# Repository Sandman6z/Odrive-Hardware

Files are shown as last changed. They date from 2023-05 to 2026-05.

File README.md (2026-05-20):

# ODriveHardware

**!Bug !Bug !Bug**

When I design my PCB project, I forked from Odrive official repository [ODriveHardware](https://github.com/odriverobotics/ODriveHardware) .
However, the PCB project under /v3 have some different with schmetic in /v3/v3.5docs.
After I find too much data, and ask AI, and other opensource projects, like `oshwhub`. They all told me that use v3.5 schmetic not the one under repository root.
Such a big oolong.

***And another one thing. The schematics of version 3.6 are basically the same as those of version 3.5. Only the voltage resistance of the capacitor has been changed due to firmware adjustments.***

---

This project is all about accuratly driving brushless motors, for cheap. The aim is to make it possible to use inexpensive brushless motors in high performance robotics projects.

If you want to get your hands on a board, check out [this post](https://hackaday.io/project/11583-odrive-high-performance-motor-control/log/40702-boards-and-development).

This repository contains the circuit board design of ODrive. The other related repositories are:
* [ODriveFirmware](https://github.com/madcowswe/ODriveFirmware): Firmware that runs on the board.
* [ODrive](https://github.com/madcowswe/ODrive): Configuration and analysis scripts that runs on a PC.

There is also [ODriveFPGA](https://github.com/madcowswe/ODriveFPGA), which contains the FPGA logic and software that runs on the FPGA based ODrive. This is not currently in development, but may be resumed at some later date.

## Odrive v3 board
The pinout from the microcontroller to the board is documented [here](https://docs.google.com/spreadsheets/d/1QXDCs1IRtUyG__M_9WruWOheywb-GhOwFtfPcHuN2Fg/edit?usp=sharing).

### ODrive v3.1 errata
* The silkscreen labels for the encoders (M0, M1) are reversed.
* The output impedence of the current amplifiers were not considered when designing the post-amplifier filters. Hence the response is about 5x slower than designed. Max allowed modulation index is therefore about 50%.

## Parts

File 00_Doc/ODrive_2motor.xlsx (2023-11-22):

Quantity | Designator | Description | Voltage - Rated | Comment | LibRef
58 | C1, C2, C3, C4, C5, C6, C7, C8, C9, C10, C11, C12, C13, C14, C15, C16, C17, C18, C22, C24, C25, C26, C27, C28, C30, C31, C32, C33, C34, C35, C36, C37, C38, C39, C40, C41, C42, C43, C45, C46, C47, C48, C49, C50, C51, C52, C53, C54, C55, C56, C57, C58, C59, C60, C61, C62, C63, C64 | Capacitor, CAP CER 82PF 100V NP0 0603, CAP CER 0.1UF 50V X7R 0603, CAP CER 4.7UF 35V X5R 0805, CAP CER 270PF 50V NP0 0603, CAP CER 2.2UF 16V X5R 0603, CAP CER 0.022UF 50V X7R 0603, CAP CER 2200PF 50V NP0 0603 |  | 2.2uF, Cap, 1uF, 10uF, 100nF, 100uF, 330uF | Cap
1 | C29 | CAP TANT 68UF 16V 20% 2312 250mOhm |  | 68uF | T495C686M016ATE250
3 | CE1, CE2, CE3 | Polarized Capacitor (Axial) |  | 470uF | Cap Pol
2 | D1, D2 | Rectifier Diode, Single, 40 V, 1 A, SOD-123FL, 2, 550 mV |  |  | MBR140SFT1G
2 | FB1, FB2 | 标称阻抗@测试频率:600Ω@100MHz;误差:±25%;直流电阻(RDC):250mΩ;额定电流:2A;电路数:1; |  | L0805, L0603 | Ferrite Bead
4 | FID1, FID2, FID3, FID4 | 1mm Fiducial with 2mm soldermask, 3mm keepout |  | MARK Point | FIDUCIAL
4 | H1, H2, H3, H4 | M3 Hole with no copper |  |  | M3 Hole
1 | J1 |  |  | XT60PB | XT60PB-F/M
1 | J2 | CONN-SMD_5P-P1.25_532610571-2 |  | SH1.0-5P | SH1.0-5P
1 | J3 | Header, 16-Pin |  | Leftheader | Header 16
2 | J14, J19 | 驱动器端 |  | MR30PW-F | MR30PW-F
1 | J23 |  |  | 2square_pads | 2square_pads
2 | J100, J101 |  |  | GH1.25-5P | GH1.25-5P
1 | L2 | INDUCTOR 22UH 1.4A 175.5 MOHM |  | 22uH | NR6028T220M
1 | LED1 | 发光颜色: |  | GREEN | LED
14 | Q2, Q4, Q6, Q8, Q10, Q12, Q14, Q16, Q18, Q20, Q22, Q24, Q25, Q27 | MOSFET – Power, Single, N-Channel, SO-8 FL 30 V, 93 A |  | NTMFS4935NT1G | MOSFET-N
55 | R1, R2, R3, R4, R6, R7, R8, R9, R10, R11, R12, R13, R14, R15, R16, R17, R18, R19, R20, R21, R22, R23, R24, R25, R26, R27, R28, R29, R30, R32, R33, R34, R35, R36, R37, R38, R39, R40, R41, R42, R43, R44, R45, R46, R47, R48, R50, R51, R52, R53, R54, R55, R56, R57, R221 | Resistor, RES SMD 0.0005 OHM 1% 3W 2512 |  | 22R, Res, Ω ±1% 100mW | Res
3 | RT1, RT2, RT3 | THERMISTOR 10K OHM NTC 0402 SMD |  | NCP15XH103F03RC | TEMP RES
1 | U2 | ARM Cortex-M4 32-bit MCU+FPU, 210 DMIPS, 1024 kB Flash, 192 kB Internal RAM, 51 I/Os, 64-pin LQFP, -40 to 85 degC, Tray |  | STM32F405RGT6 | STM32F405RGT6
1 | U3 | LP5907MFX-3.3/NOPB SOT23-5 |  | LP5907MFX-3.3/NOPB | LP5907
2 | U4, U5 | MOTOR DRIVER, 3PH, 56HTSSOP |  | DRV8301 | DRV8301
1 | U6 | DRIVER, MOSFET, HALF BRIDGE, WSON-8, 1A |  | LM5109BSD/NOPB | LM5109BSD/NOPB
1 | U7 | ANALOG DEVICES Current Sense Amplifier, Bidirectional, 1, 130 µA, NSOIC |  | AD8418WBRZ | AD8418WBRZ
1 | U8 |  |  | 1117 | 1117
1 | USB1 |  |  | USB-C 16P | USB-C 16P
1 | X1 | Crystal 8MHz ±10ppm 10pF 200 Ohm -10°C ~ 60°C Surface Mount 4-SMD, No Lead (DFN, LCC) |  | X3225 | X3225

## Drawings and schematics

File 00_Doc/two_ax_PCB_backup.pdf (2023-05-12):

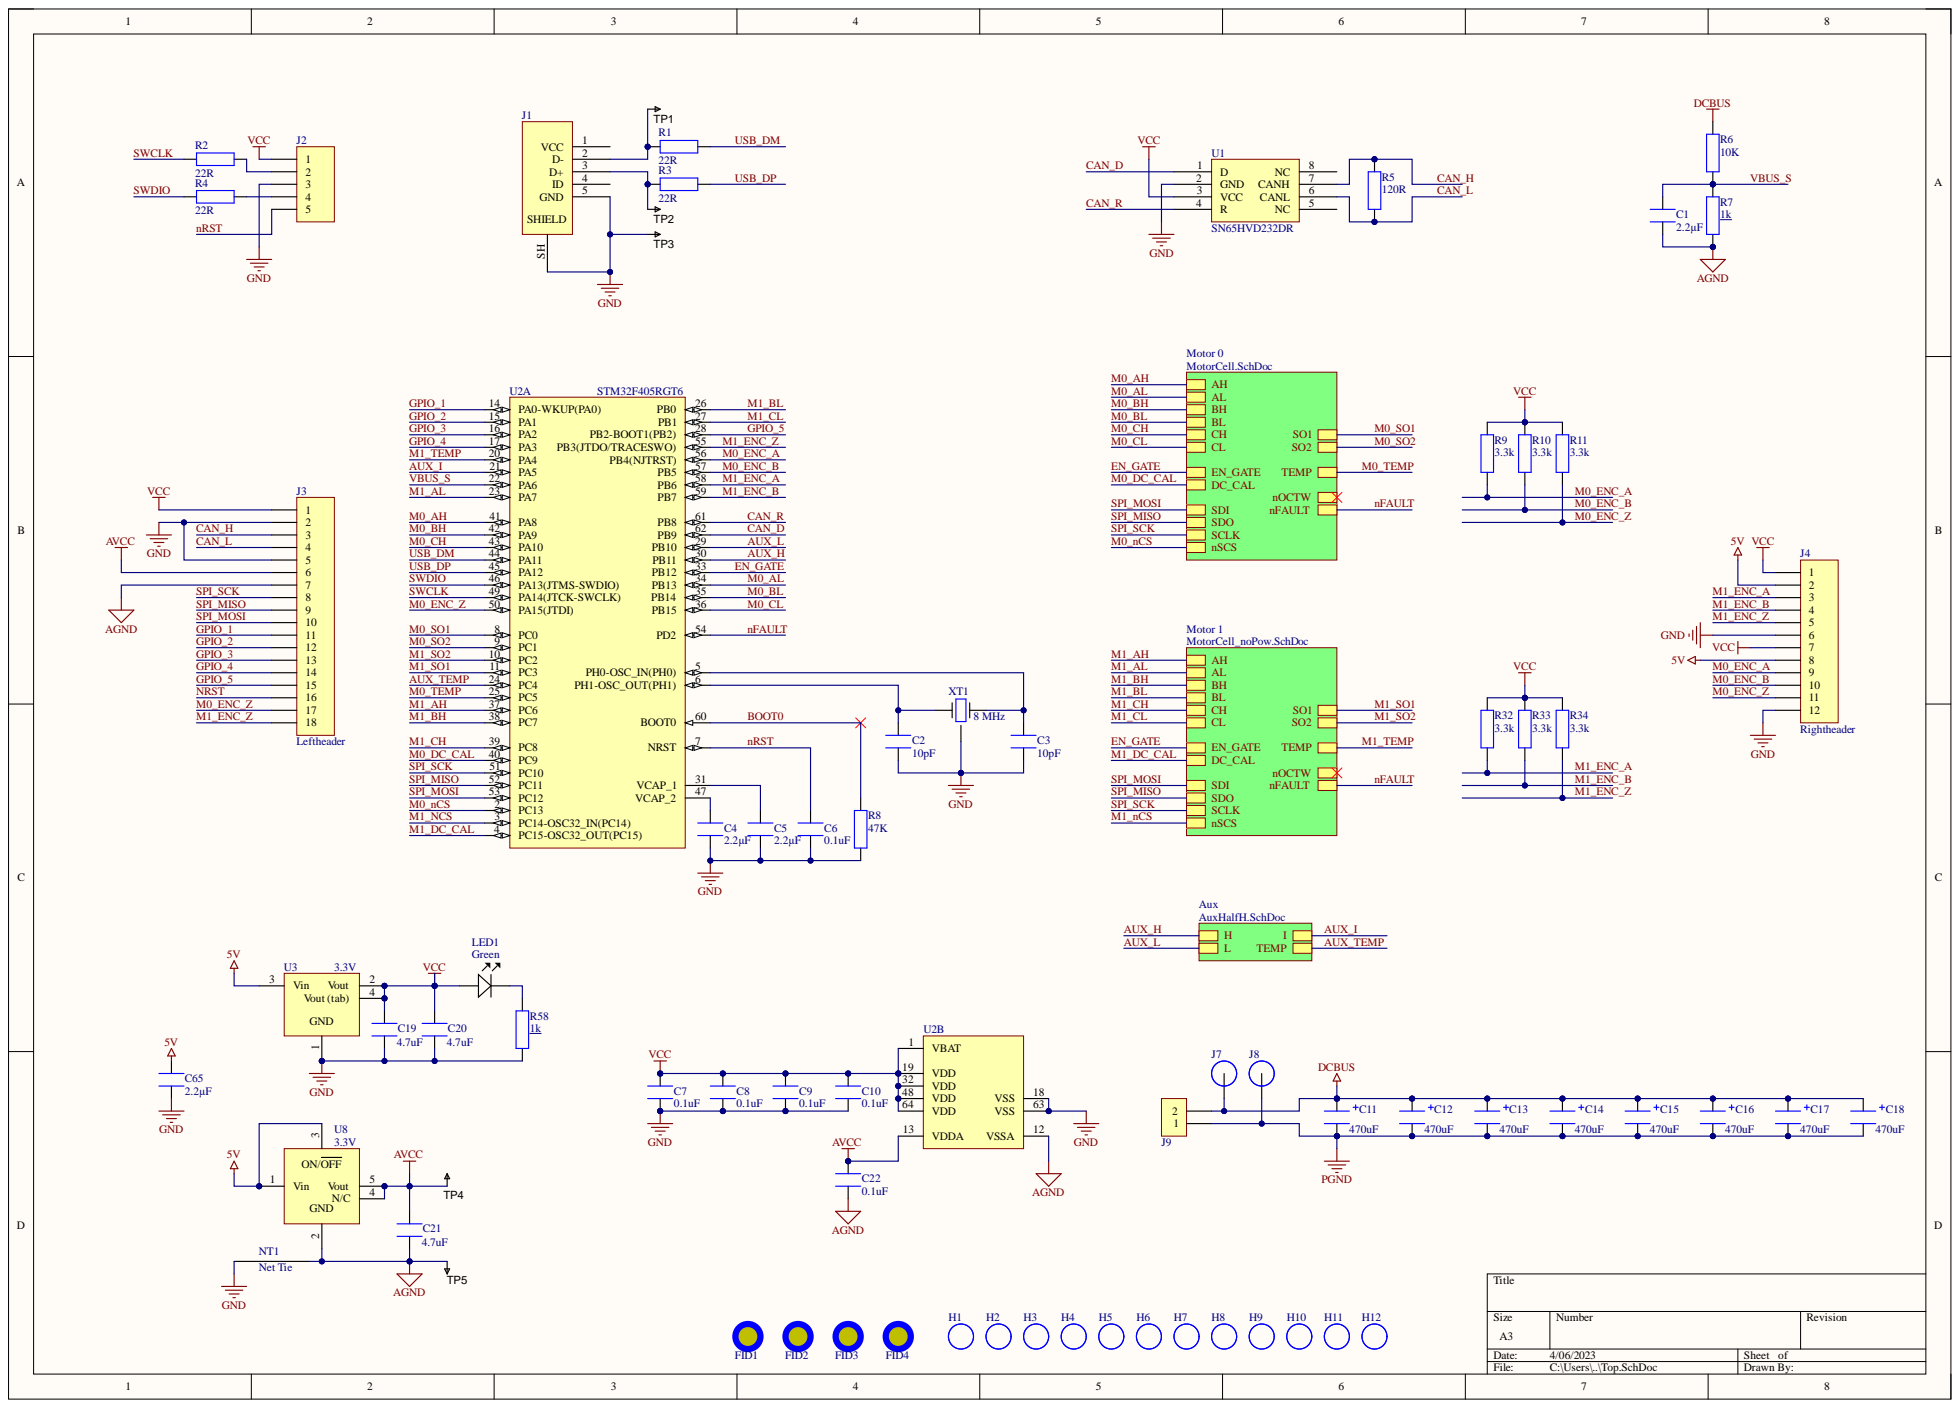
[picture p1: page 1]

3Lefthead 123456789 1011 12 13 14 15 16 17 18 | M0_A H | C A N_R

SPI_SC K | SWC L K | M0_B L N C_A
SPI_M ISO | M0_E N C_Z | M0_C L M1_E N C_B

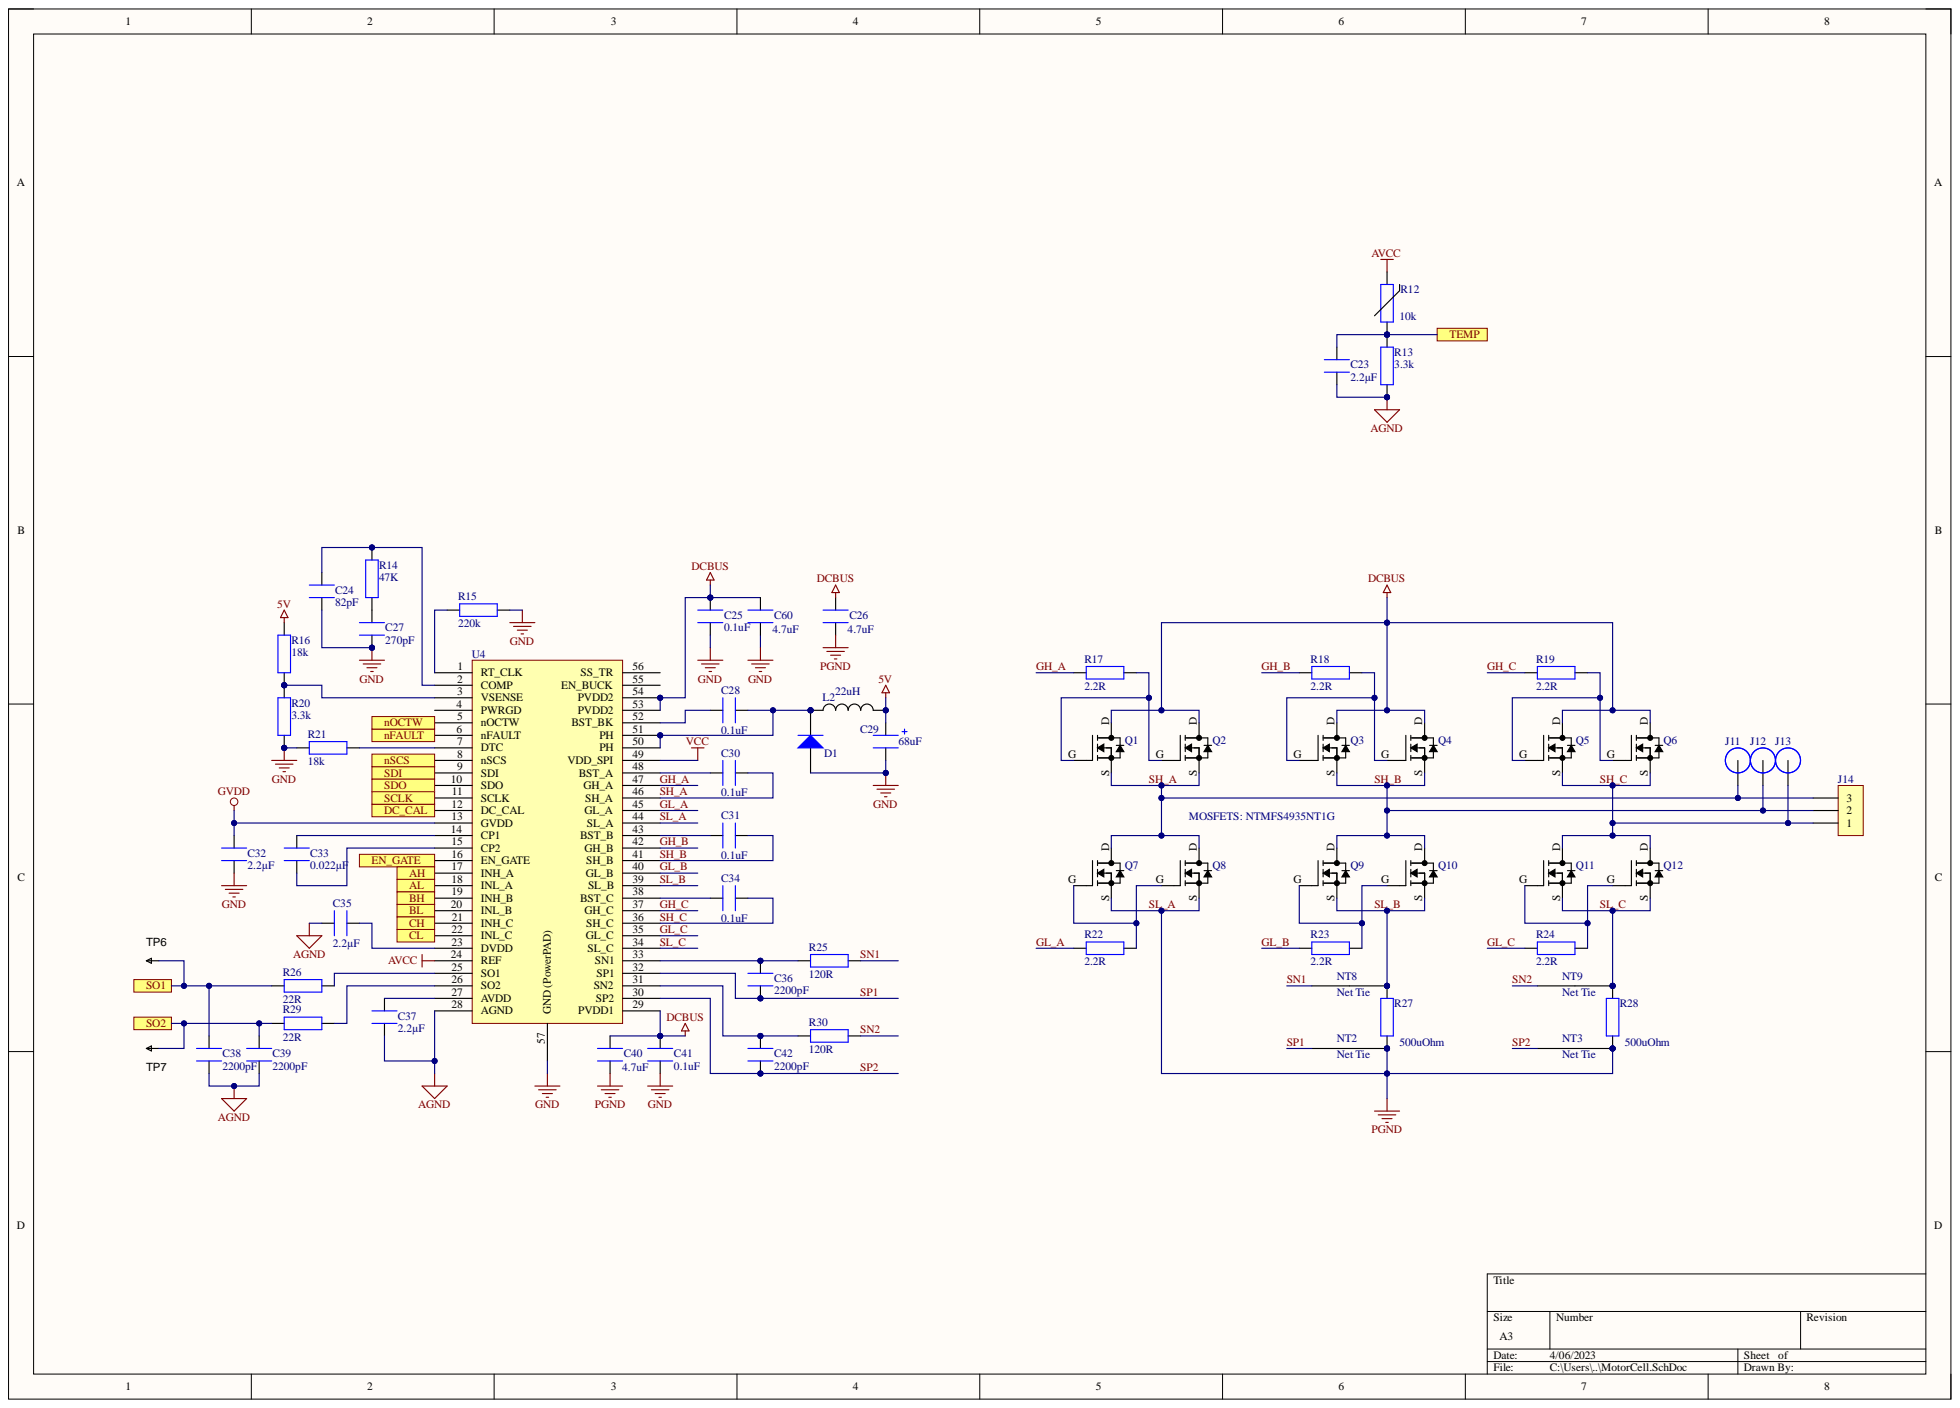
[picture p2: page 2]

PWRGD 4

nOCTW | | nOCTW 5
nFAULT | | DTC 7
nSCS | | nSCS 8
SDI | | SDI 9

nFAULT 6 | | VCC

DC_CAL | DC_CAL 12 | GL_A C31

GVDD 13 | SL_A
CP1 14
CP2 15 | | GH_B | 0.1uF

EN_GATE | | EN_GATE 16 | | SH_B

INH_A 17 | GL_B

AH | | INL_A 18 | SL_B
BH | INH_B 19

C37 | DCBUS | R30

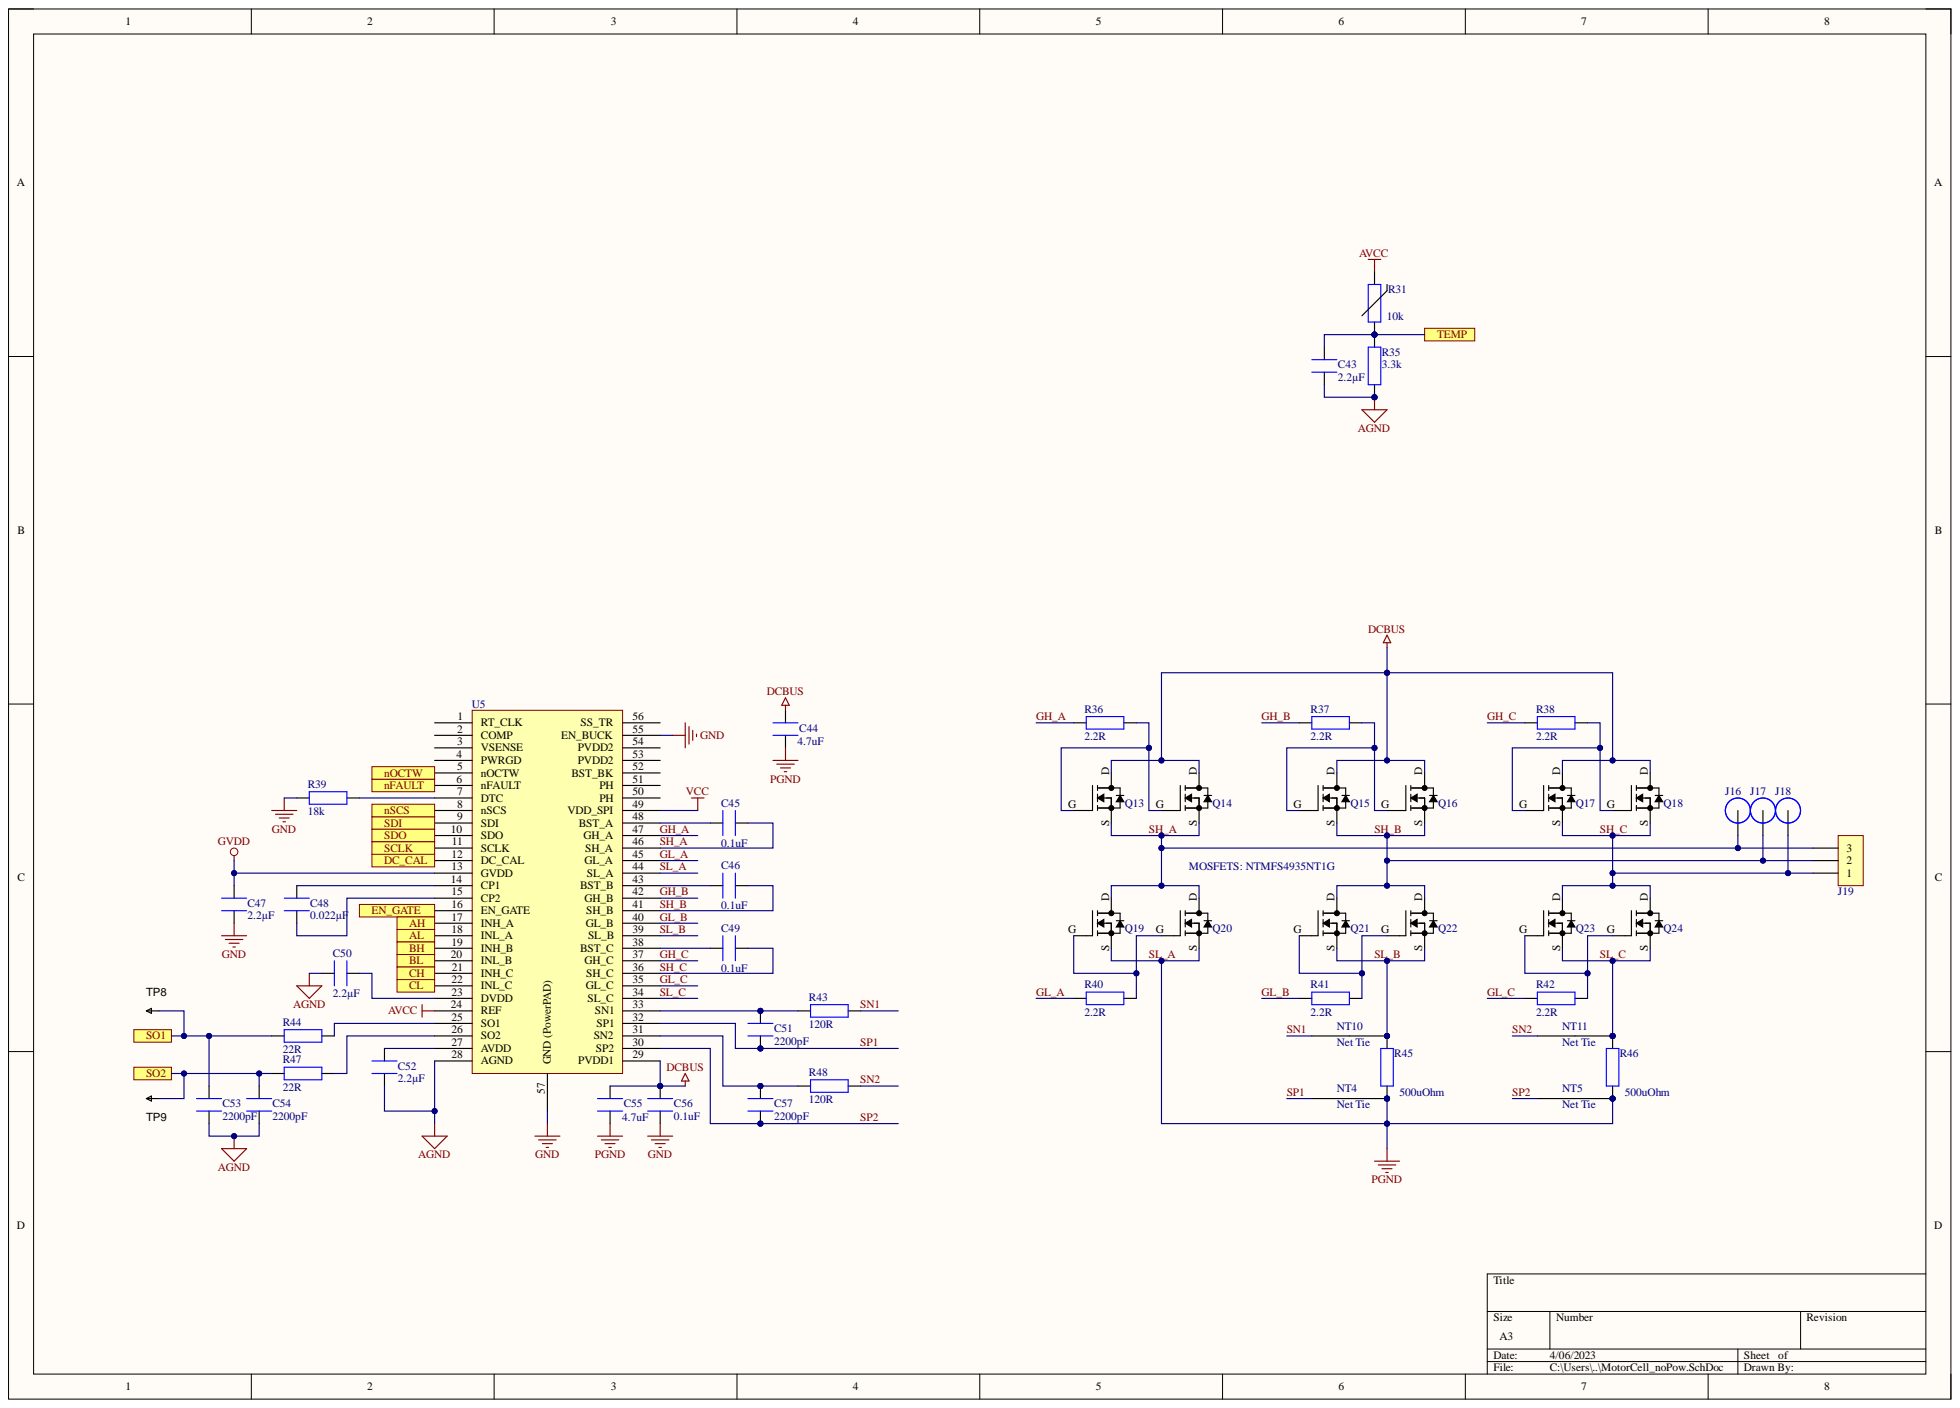
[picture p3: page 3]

nOCTW | nOCTW 5
nFAULT | DTC 7

DC_CAL | DC_CAL 12 | GL_A C46

GVDD 13 | SL_A

EN_GATE | | EN_GATE 16 | | SH_B

AH | | INL_A 18 | SL_B

INH_A 17 | GL_B

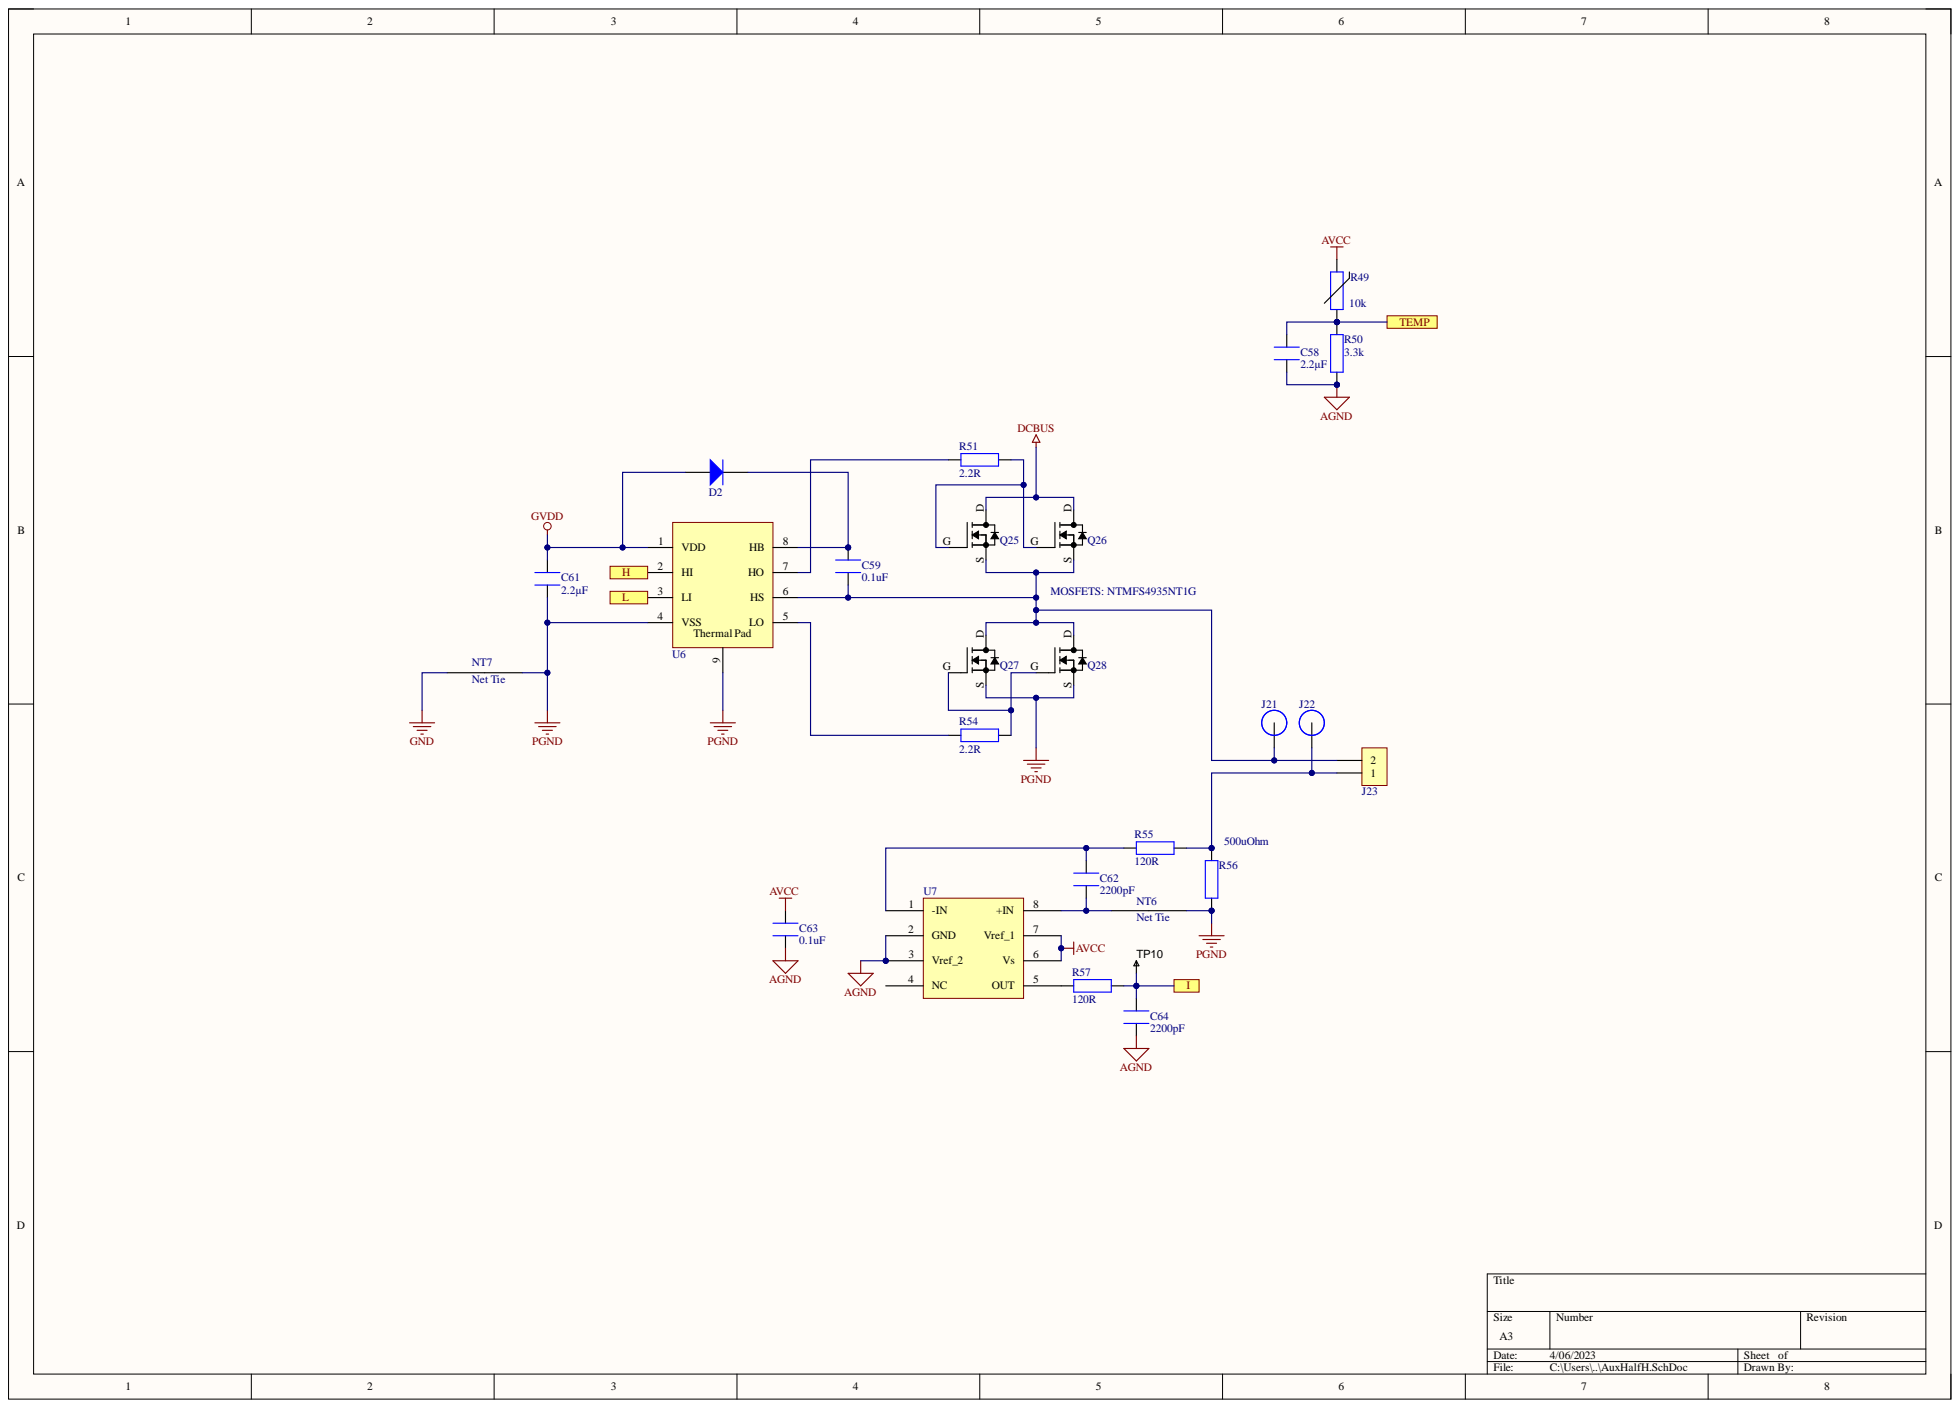
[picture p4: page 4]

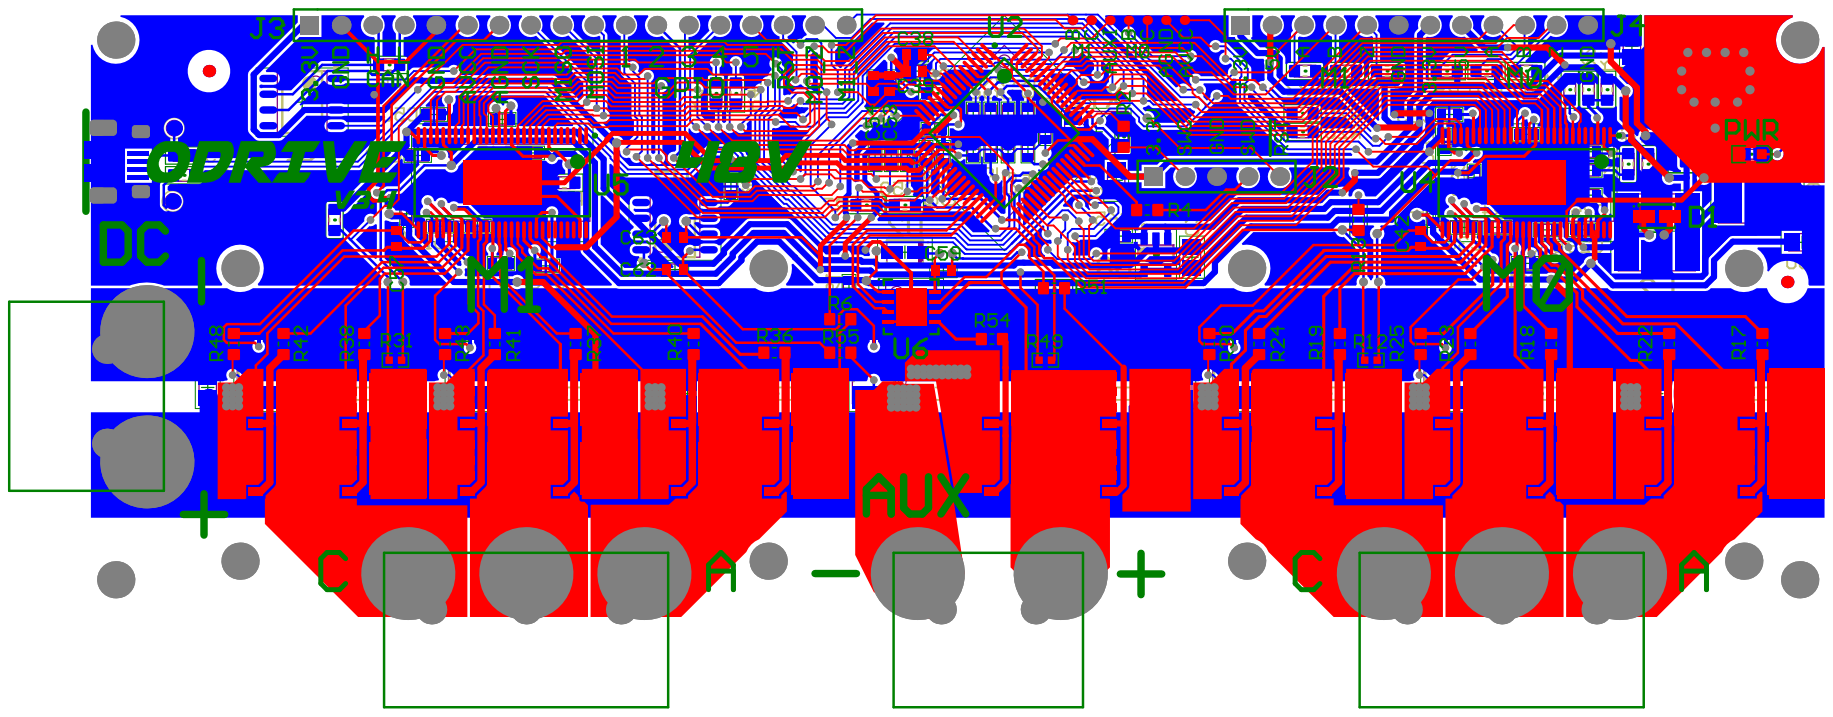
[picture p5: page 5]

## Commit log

2023-03-30 my origin prj files
    [AuxHalfH.SchDoc, BOM_v3.1.csv, BOM_v3.1_bottom.csv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]
2023-03-30 date 20230330
    [AuxHalfH.SchDoc, MotorCell.SchDoc, MotorCell_noPow.SchDoc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]
2023-03-31 change signal track width to 8 mils
2023-04-06 almost finish change .schdoc. backup .pcbdoc
    [AuxHalfH.SchDoc, MotorCell.SchDoc, MotorCell_noPow.SchDoc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]
2023-05-12 almost finish design, but ready to change MCU to 0 degree
    [AuxHalfH.SchDoc, BOM_v3.1.csv, BOM_v3.1_bottom.csv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]
2023-05-14 change power plug to XT60PB
    [MotorCell.SchDoc, MotorCell_noPow.SchDoc, Power.SchDoc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]
2023-05-14 change power plug
2023-05-15 finish track, open ploygen
    [AuxHalfH.SchDoc, ODrive_2motor.PrjPcb, Power.SchDoc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]
2023-05-16 PCB: connected all nets
    [AuxHalfH.SchDoc, MotorCell.SchDoc, MotorCell_noPow.SchDoc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]
2023-05-16 Finish design except adjust silk
    [AuxHalfH.SchDoc, MotorCell.SchDoc, MotorCell_noPow.SchDoc]
2023-05-21 before try to delete all NetTie
    [MotorCell.SchDoc, MotorCell_noPow.SchDoc, ODrive_2motor.PrjPcb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]
2023-05-23 FINISH Degisn.
    [MotorCell.SchDoc, MotorCell_noPow.SchDoc, ODrive_2motor.PrjPcb]
2023-06-05 add MR30 output ploygen cutout
    [ODrive_2motor.PrjPcb]
2023-06-25 receive PCB from HQ, change silk"48V" position.
2023-08-29 add SPI_CLK resistor necessary
    [MotorCell.SchDoc, Top.SchDoc]
2023-09-01 change sth position
    [AuxHalfH.SchDoc, MotorCell.SchDoc, MotorCell_noPow.SchDoc]
2023-09-12 move v3.x docs to new /Doc/*
    [BOM_v3.1.csv, BOM_v3.1_bottom.csv, BOM_v3.1_top.csv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]
2023-09-12 adjust PCB silk
2023-09-12 The power layer is retracted 1mm
    [ODrive_2motor.PrjPcb]
2023-11-22 Adjust all .schdoc
    [AuxHalfH.SchDoc, MotorCell.SchDoc, MotorCell_noPow.SchDoc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]
2023-11-22 change all .schdoc, ready to layout
    [Function.SchDoc, ODrive_2motor.xlsx]
2023-11-22 change DCDC Power Inductor land pattern
    [MotorCell.SchDoc, MotorCell_noPow.SchDoc, Top.SchDoc]
2023-11-23 almost finish MOSFET part layout
    [AuxHalfH.SchDoc, MotorCell.SchDoc, MotorCell_noPow.SchDoc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]
2023-11-23 ready to move lower side MOSFET Gate Resistor above all mosfet layout
2023-11-24 change LDO
    [ODrive_2motor.PrjPcb, Top.SchDoc]
2023-11-24 change stage of Program: add top sheet, original top sheet change to control sheet change 1117-3.3 to ME6217
    [AuxHalfH.SchDoc, Control.SchDoc, MotorCell.SchDoc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]
2023-11-26 move project to NEW PC
    [AuxHalfH.SchDoc, Control.SchDoc, MotorCell.SchDoc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]
2023-12-04 change AD8418 pcb package
    [AuxHalfH.SchDoc, Control.SchDoc]
2023-12-09 Completed the differential routing of the sampling resistor
    [AuxHalfH.SchDoc, Control.SchDoc, MotorCell.SchDoc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]
2023-12-11 finish signal track layout. Next is AGND layout.
    [MotorCell_noPow.SchDoc, ODrive_2motor.PrjPcb, Power.SchDoc]
2023-12-11 finish layout, tomorrow solve PCB DRC & component silk
2023-12-14 shows component silk; change finish data; change MOS pads; solve all DRC error; delete two more FTDI;
    [AuxHalfH.SchDoc, Control.SchDoc, MotorCell.SchDoc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]
2023-12-15 Due to the manufacturer’s process requirements Change the minimum via hole to 0.3mm/0.4mm or more
2024-10-03 adjust schdoc
    [AuxHalfH.SchDoc, Control.SchDoc, MotorCell.SchDoc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]
2024-11-22 NEW Branch of DRV8303. Change PCB layout
    [AuxHalfH.SchDoc, CAN.SchDoc, Control.SchDoc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]
2024-11-24 Go on layout blocks
    [CAN.SchDoc]
2024-12-04 1. Use room copy M1 from M0 2. relayout MOS part
    [Motor0.SchDoc, Motor1.SchDoc, ODrive_2motor.PrjPcb]
2024-12-15 go on layouting...
    [MCU.SchDoc, Motor0.SchDoc, Motor1.SchDoc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]
2024-12-16 adjust board size
2024-12-23 change Buck DC-DC layout & position
    [ODrive_2motor.PrjPcb, Odrive.PcbLib, Power.SchDoc]
2024-12-30 layout 3V3 power
    [Motor0.SchDoc, Motor1.SchDoc, Others.SchDoc]
2024-12-31 layout POWER Layer
2025-01-02 layouting MCU GND
    [ODrive_2motor.PrjPcb]
2025-01-04 layout almost finish, left put silk.
    [AuxHalfH.SchDoc, CAN.SchDoc, MCU.SchDoc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]
2025-01-05 1. finish design; 2. remove pcblib; 3. add bomdoc
    [ODrive_2motor.PrjPcb, Odrive.PcbLib, Others.SchDoc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]
2025-01-06 他妈的气得我，必须得用中文写了，英文不会骂，操 AD老早就出了的自定义形状焊盘板厂DFM、GERBER软件识别不了，整了个我阻焊没有开窗，改了半天，在AD里看gerber和solder都没问题，用HQDFM才看出来不对劲，一看到华秋那个逼软件老掉牙，就猜到是这个问题，从onsemi官网下载的SamacSys格式的把MOS的大焊盘分成了若干了一样的，这个在DFM里看就能看出来了，他妈的傻逼老掉牙软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
    [AuxHalfH.SchDoc, Motor0.SchDoc, Motor1.SchDoc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]
2025-01-22 change NETTIE pcblib & update PCB
    [AuxHalfH.SchDoc, Motor0.SchDoc, Motor1.SchDoc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]
2025-11-26 change(footprint): use wurth footprint
    1. change Res.&Cap. 0402 0603
    2. change R2512
    [AuxHalfH.SchDoc, MCU.SchDoc, Motor0.SchDoc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]
2025-11-26 modify(footprint, layout):
    1. update footprint from schdocs
    2. adjust layout
2025-11-26 update(docs, variable): update related files
    [ODrive_2motor.PrjPcb]
2026-03-03 Move files into folders according to different categories
    [AuxHalfH.SchDoc, BOM_v3.1.csv, BOM_v3.1_bottom.csv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]
2026-05-20 Update README with PCB project and schematic notes
    Clarify PCB project details and schematics for ODrive.
2026-05-20 Update README with PCB project information
    Clarified PCB project details and corrected grammar in README.
